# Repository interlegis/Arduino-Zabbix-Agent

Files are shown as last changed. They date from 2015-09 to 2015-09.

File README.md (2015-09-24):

# Arduino-Zabbix-Agent

Using an Arduino Uno v3 and a Zabbix Server to monitor a data center environment.

It's a Zabbix Agent tested and running successfully.

* [Materials](#materials)
* [Schematic](#schematic)
* [More info](#more-info)
  * [DHT11](#dht11)
  * [DS18b20](#ds18b20)
  * [PIR](#pir)
  * [Soil humidity sensor](#soil-humidity-sensor)
  * [Led](#led)
  * [Observations](#observation)
* [How to use](#how-to-use)
* [Keys used on Zabbix](#keys-used-on-zabbix)
* [On the code](#on-the-code)
* [Example](#example)

## Materials:

- Arduino Uno v3
- Ethernet Shield
- Arduino Sensor Shield*
- DHT11 (or similar) and one 10k resistor
- DS18b20 (or similar) and one 4.7k resistor
- PIR (Passive infrared sensor/Motion detector)
- Soil humidity sensor
- One led and one 1k resistor

###### *A new shield may be built by yourself.

## Schematic:
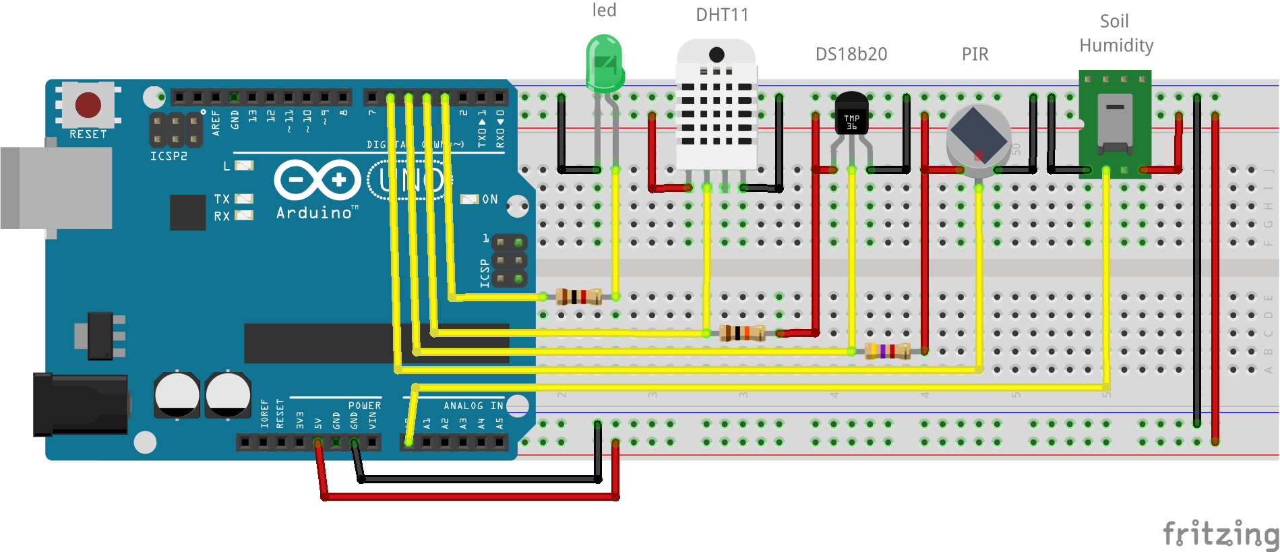
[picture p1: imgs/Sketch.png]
Schematic

Schematic done using [Fritzing](http://www.fritzing.org).

### More info:

#### `DHT11`
This sensor can measure the air temperature and humidity. It doesn't need to be calibrated. It is recommended to take 1 sample per second or less. It returns one `int` for each data. The temperature is in Celsius. A 10k resistor must be connected to pins Vcc and Signal.

#### `DS18b20`
This sensor is responsible for measuring the air temperature and returning a `float`. It is fast enough to take one sample for each Arduino cpu clock. It doesn't need to be calibrated and is water-proof. The library `OneWire` is used for reading its data. This means it is possible to connect multiple DS18b20 sensors on a single Arduino port. The temperature is in Celsius. A single 4.7k resistor must be conected between Vcc and the pin connected to one or more sensor.

#### `PIR`
Plug and play sensor. Doesn't need resistor or adjustments. Its signal must be connected to an Arduino port and that's all. Returns `1` when detects motion and `0` when nothing is detected.

#### `Soil humidity sensor`
Tricky sensor. It returns `1` when it's dry and `0` when it detects humidity. Its output is digital. The sensibility must be adjusted by turning a small screwdriver on the sensor.

#### `Led`
Be careful! Leds are extremely fragile. It needs a 1k resistor in series to make it work. The brightness may vary depending on the model and color. In this project, the led is turned on when the Arduino receives a command and
is turned off when the value is returned to the server.

### Observations:
Some results are kept for a few seconds to avoid oscillations from the sensors. For example, PIR may get a positive (motion) result and then a null (motion stopped) before Zabbix check. So its value is kept for a few seconds on `1` to allow Zabbix to have enough time to read it.

DS18b20 function is checked on every loop, but the sensors are read only once every 15 seconds. If the request is made on less than 15 seconds after the last one, it simply replies the variable value, making the response much faster.

All temperature are in Celsius.
To convert to Fahrenheit:
```
Temp F = 1.8*(Temp C) + 32
```

## How to use:

Check pins used.
Upload the code to the Arduino.
Add an item on Zabbix Server.
 - Type: Zabbix agent.
 - Key: The key for each sensor (`q`, `w`, `e`, `r`, `t` etc).
 - It is recommended to check each item on not less than once a minute.

## Keys used on Zabbix:

* q - soil humidity
* w - air temperature on DHT11
* e - air humidity on DHT11
* r - air temperature on DS18b20 with serial number ending with 17
* f - air temperature on DS18b20 with serial number ending with B6
* v - air temperature on DS18b20 with serial number ending with D3
* t - motion detector

## On the code:

Set the IP address, the gateway and the MAC address to be used by the agent.

Check how many sensors will be used and add them to the code if necessary. To do this:
* Set a pin using `#define`.
* Write a function to read the sensor if necessary.
* Choose a letter to be used as a command for each sensor function. Make sure the letter is not used anywhere else!
* On `parseCommand`, add the function to be executed when receiving the command defined on the step before.

__*Pins 10, 11, 12 and 13 cannot be used. They are used by the ethernet shield*.__

Pin 3 is the led.

Pin 4 is the DHT11.

Pin 5 is one or more DS18b20 (using OneWire).

Pin 6 is the PIR.

Pin A0 is the soil humidity sensor.

## Example:

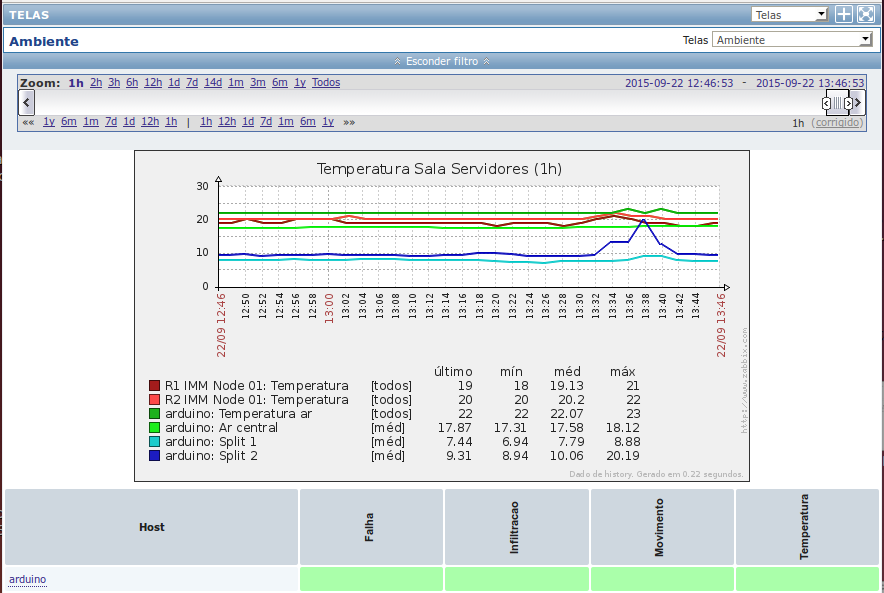
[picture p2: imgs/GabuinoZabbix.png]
Zabbix


---
Zabbix Agent on Arduino Uno v3

By [GabRF.com](http://gabrf.com)

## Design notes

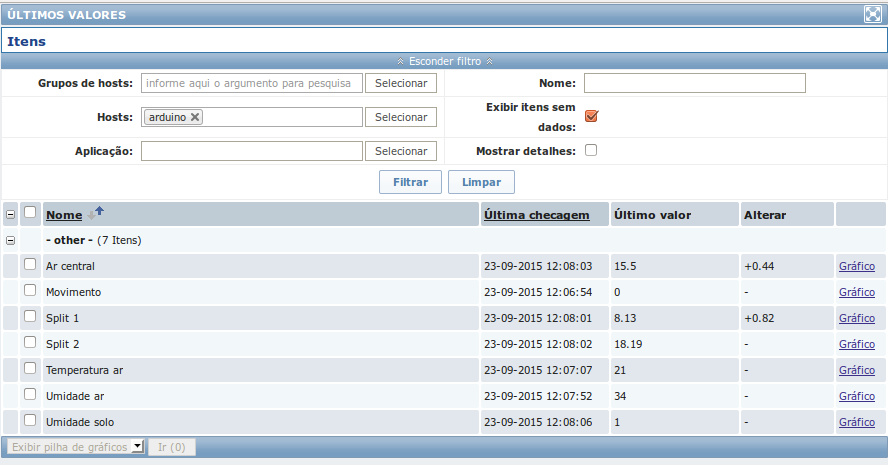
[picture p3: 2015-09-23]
imgs/GabuinoZabbixRecent.png

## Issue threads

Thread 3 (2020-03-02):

Error compile

fvancan, 2020-03-02:
Hi,
I try to compile, but received this error

sketch_mar02b.ino:34:1: error: ‘dht’ does not name a type
sketch_mar02b.ino: In function ‘void readDHT11()’:
sketch_mar02b.ino:130:14: error: expected primary-expression before ‘.’ token
sketch_mar02b.ino:132:12: error: ‘DHTLIB_OK’ was not declared in this scope
sketch_mar02b.ino:134:12: error: ‘DHTLIB_ERROR_CHECKSUM’ was not declared in this scope
sketch_mar02b.ino:137:12: error: ‘DHTLIB_ERROR_TIMEOUT’ was not declared in this scope
sketch_mar02b.ino:144:15: error: expected primary-expression before ‘.’ token
sketch_mar02b.ino:145:15: error: expected primary-expression before ‘.’ token

Could you help me?

GabrielRF, 2020-03-12:
@fvancan
What lib are you using for DHT?
By the time I commited the code I failed on uploading libs

fvancan, 2020-03-16:
> @fvancan
> What lib are you using for DHT?
> By the time I commited the code I failed on uploading libs

Hi @GabrielRF!

I'm using the lib from this site https://github.com/adafruit/DHT-sensor-library
Could you committed yours lib, please?

Regards,

septianerikas, 2022-10-24:
zabbix_sensor_agent_interlegis.ino: In function 'void readDHT11()':
zabbix_sensor_agent_interlegis:132:12: error: 'DHTLIB_OK' was not declared in this scope
       case DHTLIB_OK:

kindly share your DHT library please.

1641624, 2023-03-29:
Does someone already know which library was used?

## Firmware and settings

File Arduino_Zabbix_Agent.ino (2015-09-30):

//******************************************************************************
//* Purpose : Zabbix Sensor Agent - Environmental Monitoring Solution *
//* Git : https://github.com/interlegis/arduino-zabbix-agent
//* Author :  Gabriel Ferreira and Marco Rougeth *
//* https://github.com/gabrielrf and
//* https://github.com/rougeth
//* Adapted from : Evgeny Levkov and Schotte Vincent *
//* Credits: *

#include <SPI.h>
#include <Ethernet.h>
#include <dht.h>
#include <OneWire.h>
#include <string.h>

//----------------------------- Network settings -------------------------------
byte mac[] = { 0x90, 0xA2, 0xDA, 0x00, 0xE3, 0x1B };
//IPAddress ip(10, 1, 2, 235);
IPAddress ip(10, 1, 2, 61);
IPAddress gateway(10, 1, 2, 254);
IPAddress subnet(255, 255, 255, 0);

//------------ Pins 10, 11, 12 e 13 are used by ethernet shield! ---------------
#define MAX_CMD_LENGTH 25
#define LED_PIN 3              // LED pin with 1k resistor
#define DHT11_PIN 4            // DHT11 pin with a 10k resistor
#define ONE_WIRE_PIN 5         // One wire pin with a 4.7k resistor
#define PIR_PIN 6              // PIR pin
#define SOIL_PIN A0            // Soil humidity sensor pin

EthernetServer server(10050);
EthernetClient client;
OneWire ds(ONE_WIRE_PIN);
dht DHT;

boolean connected = false;
byte i;
byte present = 0;
byte type_s;
byte data[12];
byte addr[8];
double temp = 0;                // Temperature
double umid = 0;                // Humidity
float celsius;
float oneWire17 = 0;
float oneWireB6 = 0;
float oneWireD3 = 0;
String cmd;                     //FOR ZABBIX COMMAND
String serialNum;
int counter = 1;                // For testing
int chk;
int presence = 0;
int lastPresence = 0;
int soil = 0;                   // Soil humidity
int limite = 1;                 // Command size. Using 1 for better performance.
int waitTime = 15000;           // Default waiting time before reading sensor again.
int pirWaitTime = 200000;       // Default waiting time for PIR.
unsigned long dhtLastCheck = 0;
unsigned long pirLastCheck = 0;
unsigned long oneWireLastCheck = 0;

// Read all DS18b20 and saves the result on variables every 15 seconds.
void readOneWire() {
  if (millis() - oneWireLastCheck > waitTime) {
    if ( !ds.search(addr)) {
      //Serial.println("No more addresses.");
      ds.reset_search();
      //delay(250);
      return;
    }
    if (OneWire::crc8(addr, 7) != addr[7]) {
      Serial.println("CRC is not valid!");
      return;
    }
    switch (addr[0]) {
      case 0x10:
        type_s = 1;
        break;
      case 0x28:
        type_s = 0;
        break;
      case 0x22:
        type_s = 0;
        break;
      default:
        Serial.println("Device is not a DS18x20 family device.");
        return;
    }
    ds.reset();
    ds.select(addr);
    ds.write(0x44, 1);      // start conversion, with parasite power on at the end
    //delay(1000);          // maybe 750ms is enough, maybe not
    // we might do a ds.depower() here, but the reset will take care of it.
    present = ds.reset();
    ds.select(addr);
    ds.write(0xBE);         // Read Scratchpad
    for ( i = 0; i < 9; i++) {           // we need 9 bytes
      data[i] = ds.read();
    }
    int16_t raw = (data[1] << 8) | data[0];
    if (type_s) {
      raw = raw << 3; // 9 bit resolution default
      if (data[7] == 0x10) {

        raw = (raw & 0xFFF0) + 12 - data[6];
      }
    } else {
      byte cfg = (data[4] & 0x60);

      if (cfg == 0x00) raw = raw & ~7;      // 9 bit resolution, 93.75 ms
      else if (cfg == 0x20) raw = raw & ~3; // 10 bit res, 187.5 ms
      else if (cfg == 0x40) raw = raw & ~1; // 11 bit res, 375 ms
    }
    celsius = (float)raw / 16.0;
    //Serial.print(celsius);
    //Serial.println(" Celsius");
    serialNum = String(addr[7], HEX);
    if (serialNum == "17") oneWire17 = celsius;
    else if (serialNum == "b6") oneWireB6 = celsius;
    else if (serialNum == "d3") oneWireD3 = celsius;
    // If Fahrenheit needed, (Fahrenheit = Celsius * 1.8) + 32;

    oneWireLastCheck = millis();
  }
}

// Read DHT11 every 15 seconds and save values on variables
void readDHT11() {
 if (millis() - dhtLastCheck > waitTime) {
    chk = DHT.read11(DHT11_PIN);
    switch (chk) {
      case DHTLIB_OK:
        break;
      case DHTLIB_ERROR_CHECKSUM:
        Serial.print("Checksum error,\t");
        break;
      case DHTLIB_ERROR_TIMEOUT:
        Serial.print("Time out error,\t");
        break;
      default:
        Serial.print("Unknown error,\t");
        break;
    }
    temp = DHT.temperature;
    umid = DHT.humidity;
    dhtLastCheck = millis();
  }
}

// Read command received.
void readTelnetCommand(char c) {
  if (cmd.length() == MAX_CMD_LENGTH) {
    cmd = "";
  }
  cmd += c;
  if (c == '\n' || cmd.length() == limite) {
    parseCommand();
  }
  else {
  }
}

// Read soil humidity sensor.
void readSoil() {
  soil = digitalRead(SOIL_PIN);
}

// Read PIR and if positive, keep the value for pirWaitTime seconds.
void readPresence() {
  if (digitalRead(PIR_PIN)) {
    pirLastCheck = millis();
    lastPresence = 1;
  }
  if (digitalRead(PIR_PIN) && (lastPresence)) {
    presence = 1;
  }
  else {
    if (millis() - pirLastCheck > pirWaitTime) {
      presence = 0;
      lastPresence = 0;
    }
  }
}

//Commands received by agent on port 10050 parsing
void parseCommand() {
  if (cmd.equals("")) {  }
  else {
    counter = counter + 1;
    Serial.print(" Tempo: ");
    Serial.print(millis() / 1000);
    Serial.print("\t");
    Serial.print("Cmd: ");
    Serial.print(cmd);
    Serial.print("\t\t");
    Serial.print("Resposta: ");
    // AGENT ping
    if (cmd.equals("p")) {
      server.println("1");
    } // Agent version
    else if (cmd.equals("l")) {
      //Serial.println("Version");
      server.println("Arduino Zabbix Agent 1.0");
      delay(100);
    } // Agent soil humidity
    else if (cmd.equals("q")) {
      readSoil();
      Serial.print(soil);
      server.println(soil);
      // NOT SUPPORTED
    } // Agent air temperature
    else if (cmd.equals("w")) {
      readDHT11();
      Serial.print(temp);
      server.println(temp);
      dhtLastCheck = millis() - waitTime;
    } // Agent air humidity
    else if (cmd.equals("e")) {
      readDHT11();
      server.println(umid);
      Serial.print(umid);
    } else if (cmd.equals("r")) {
      server.println(oneWire17);
      Serial.print(oneWire17);
    } else if (cmd.equals("f")) {
      server.println(oneWireB6);
      Serial.print(oneWireB6);
      oneWireLastCheck = oneWireLastCheck - (waitTime/3);
    } else if (cmd.equals("v")) {
      server.println(oneWireD3);
      Serial.print(oneWireD3);
      oneWireLastCheck = oneWireLastCheck - (waitTime/3);
    } else if (cmd.equals("t")) {
      server.println(presence);
      Serial.print(presence);
      oneWireLastCheck = oneWireLastCheck - (waitTime/3);
      pirLastCheck = millis() - pirWaitTime;
    } else { // Agent error
      //server.print("ZBXDZBX_NOTSUPPORTED");
      //server.print("Error");
    }
    cmd = "";
    Serial.println("");
    client.stop();
  }
}

// The loop that Arduino runs forever after the setup() function.
void loop() {
  client = server.available();
  if (client) {
    if (!connected) {
      Serial.println("Conection not available");
      client.flush();
      connected = true;
      client.stop();
    }
    if (client.available() > 0) {
      Serial.println("Client Available");
      Serial.println("Conection ok");
      int clientread = client.read();
      Serial.print(clientread);
      char charcr = clientread;
      digitalWrite(LED_PIN, HIGH);
      readTelnetCommand(clientread);
      digitalWrite(LED_PIN, LOW);
    }
  }
  if (millis()%2) {
    readPresence();
  }
  else {
    readOneWire();
  }
}

// This function runs once only, when the Arduino is turned on or reseted.
void setup() {
  pinMode(LED_PIN, OUTPUT);
  Serial.begin(9600);
  //Serial.begin(115200);
  pinMode(SOIL_PIN, INPUT);
  Ethernet.begin(mac, ip, gateway, subnet);
  server.begin();
  Serial.println("Setup");
  delay(1000);
}

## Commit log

2014-10-04 Zabbix Agent on Arduino
2014-10-06 Bug fixes
    Memory leak corrected.
    [Arduino_Zabbix_Agent.ino]
2015-09-03 Update Arduino_Zabbix_Agent.ino
    typo
2015-09-21 Added DS18b20 sensor and minor fixes
    [Arduino_Zabbix_Agent.ino]
2015-09-23 Readme and Schematic
    Update readme and Schematic added to readme.
    Schematic done using Fritzing.
    [Sketch.fzz]
2015-09-23 Sketch fix
    [Sketch.fzz]
2015-09-24 Improved performance | Improved readme
    OneWire won’t be read on every single request. Responses are much
    faster now.
    [Arduino_Zabbix_Agent.ino]
2015-09-30 False positives on PIR fixed
    PIR was sending false positives. Might be fixed now.
    Also small improvements on answer speed.
    [Arduino_Zabbix_Agent.ino]
